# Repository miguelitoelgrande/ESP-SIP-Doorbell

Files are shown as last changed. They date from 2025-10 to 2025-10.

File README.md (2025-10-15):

# ESP SIP Doorbell - Getting Started Guide
Attach an ESP8266 or ESP32 board to a classic doorbell and use SIP protocol to make the phones connected to a FritzBox ring.

This ESP8266-based doorbell connects to your FritzBox (or other SIP server) and makes instant phone calls when triggered. The device prioritizes the doorbell function above all else - when powered on or reset, it immediately attempts to connect and ring your phones.

- Hardware setup can be found here: https://www.reichelt.de/magazin/projekte/smarte-tuerklingel/
- or: https://www.heise.de/select/ct/2017/17/1502995489716437
- or: https://www.heise.de/select/ct/2018/17/1534215254552977
- or: http://www.roehrenkramladen.de/Tuerklingel/TK-FB-V1a-1.html
There are probably even board schematics around, but breadboard-style wiring should be fine.

And again: This ESP-Software is **not** TR064 based, but uses *SIP* for simplicity and security.

---

## ⚡ Key Features
- Immediate SIP call on wake/reset: SIP initialization and call within seconds
- All configuration and management happens AFTER the call. Also the first configuration
- Starts an Access Point for the initial configuration (see below)
- **Serial Debug**: Traditional UART debugging at 115200 baud
- **WebSerial**: Browser-based debug console accessible via web interface (especially, if you cannot physically connect to the board)
- Both can be enabled/disabled independently via configuration
- Persistent storage of last 100 doorbell events
- Automatic time sync after initial call; configurable NTP server (default: pool.ntp.org) and timezone offset
- Configurable timezone offset
- **Smart Power Management**: Configurable deep sleep timeout (default: 180 seconds)
- Set timeout to 0 to disable deep sleep
- Wake on hardware reset (doorbell button)
- **Flexible Network Configuration**: DHCP or static IP, WiFi station mode for normal operation
- **Automatic AP fallback** when WiFi connection fails
- Web-based configuration portal, status, past events, WebSerial always available
- **Complete SIP Integration**: Compatible with FritzBox and standard SIP servers
- Configurable ring duration (5-120 seconds) and dial text

---

## 🚀 First-Time Setup

### Hardware and Software Requirements
- ESP8266 board (ESP-01, NodeMCU, Wemos D1, etc.)
- or ESP32 board (e.g. a tiny ESP32-C3 SuperMini will do)
- USB power or battery power supply
- Adapter to connect to existing, physical door bell circuit (with AC tansformer)
- Connect the Doorbell Button circuit between GPIO14 and GND. Will bring the ESP out of Light Sleep
- OBSOLETE: Doorbell button connected between RST (Reset) and GND - TODO: Might change to better solution
- OBSOLETE: For deep sleep wake: RST pin connected to doorbell button circuit
- Compile with **Arduino IDE** (.ino is the Sketch File, add the SIP.h and SIP.cpp)

### Initial Configuration

0. **Register Settings at FritzBox**
   - Ensure, you have your WIFI SSID and password at hand.
   - !! Needs to be a static IP in main Fritz network, not guest !!
   - You will also need the IP of your FritzBox (192.168.xx.xx).
   - If you decide to do the Fritzbox-sided registration of the IP-Doorbell first (see below), you should have the SIP user and SIP password as well. Otherwise, enter later.

2. **Power on the ESP8266**
   - On first boot, default WiFi credentials won't work
   - Device automatically starts AP mode for configuration

3. **Connect to the Configuration AP**
   - SSID: **`ESP-Doorbell-Config`**
   - Password: **`12345678`**
   - _Note: If you connect with your mobile phone, you might have to confirm, you want to stay connected to a netwok without internet access!_
   - Device IP: `192.168.4.1` (use Chrome), e.g. on a mobile phone in **same** network

4. **Open the Configuration Portal**
   - Open browser and navigate to: **`http://192.168.4.1`**
   - You'll see the main configuration page

5. **Configure WiFi Settings**
   - **SSID**: Your home WiFi network name
   - **Password**: Your WiFi password
   - **Hostname**: Device hostname (default: ESP-Doorbell)

6. **Configure Network Settings**
   - **Use DHCP**: Check for automatic IP (static IP recommended for most users - speeds up the startup)
   - **Static IP**: the static IP of the doorbell (e.g., 192.168.178.123), if DHCP is unchecked.. TODO: could be removed at all?
   - **Router/Gateway**: Your FritzBox IP (e.g., 192.168.178.1)
   - **Subnet Mask**: Usually 255.255.255.0

7. **Configure SIP Settings** (Critical!)
   - **SIP Port**: Usually 5060 (FritzBox default)
   - **SIP User**: SIP username as configured at FritzBox (e.g., "tuerklingel")
   - **SIP Password**: SIP password from FritzBox
   - **Dial Number**: Number to dial (e.g., **9 to ring at all phones, or specific extension, e.g. "1" - as configured at FritzBox)
   - **Dial Text**: Caller ID text (e.g., "Front Door")
   - **Ring Duration**: How long phones should ring (default: 30 seconds)

8. **Configure Debug Options**
   - **Serial Debug**: Enable for USB/UART debugging
   - **WebSerial Debug**: Enable for browser-based debug console
   - Both can be enabled simultaneously

9. **Configure Time Settings**
   - **NTP Server**: Time server (default: pool.ntp.org)
   - **Timezone Offset**: Seconds from UTC
     - UTC+1 (CET): 3600
     - UTC+2 (CEST): **7200**

10. **Configure Power Management**
   - **Sleep Timeout**: Seconds before deep sleep (default: 180)
   - Set to 0 to disable deep sleep
   - Device stays awake longer when accessed via web interface

11. **Save Configuration**
    - Click "Save & Reboot"
    - Device will reboot in 10 seconds
    - If WiFi connection succeeds, AP mode will be disabled
    - If WiFi fails, AP mode will remain active for reconfiguration
---

## 📞 FritzBox SIP Configuration for the doorbell

Other VoIP capable routers potentially similar (or worldwide VoIP services?)

### Important: The Doorbell needs a fixed IP address. Register at FritzBox after first connect to WIFI and use above.

### Creating a Doorbell Extension

 ### **Log into FritzBox**
   - Navigate to `http://fritz.box`
   - Login to your **FritzBox** admin portal.
   - Go to **"Telephony"** -> **"Telephony Devices"** -> **"Configure New Device"**.
   - Choose **"Door intercom system"** and **Next**.

   ### **Register new Device/SIP credentials**
      + Port: "LAN / Wi-Fi (IP door intercom system)".
      + Name: Tuerklingel.
   
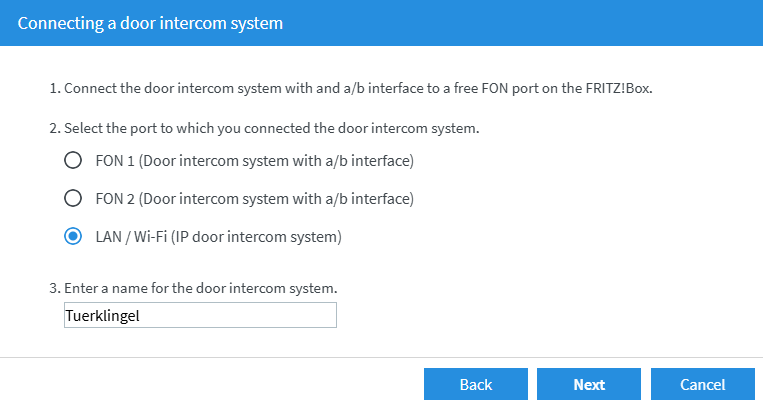
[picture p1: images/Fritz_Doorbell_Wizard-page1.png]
image info
   
   Register a new "Intercom" IP Device

   ### SIP user and Password (also note the IP of your FritzBox)
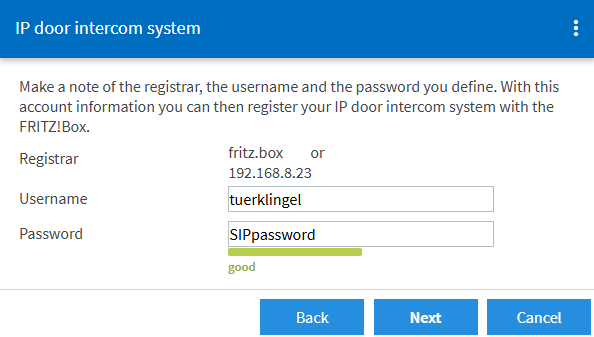
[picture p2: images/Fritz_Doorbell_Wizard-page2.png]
image info
   

   ### We need this telephone number for the configuration on the ESP.
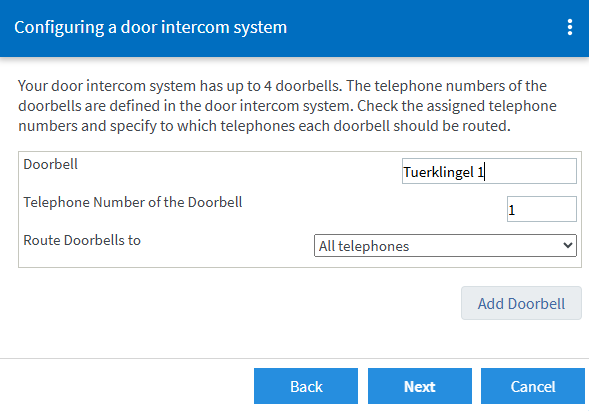
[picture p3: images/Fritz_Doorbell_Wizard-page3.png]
image info
   

   ### You could route this to all phones or a subset of phones.
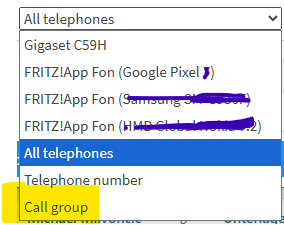
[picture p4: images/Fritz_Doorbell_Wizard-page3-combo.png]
image info
   

   ### Check the Settings and apply
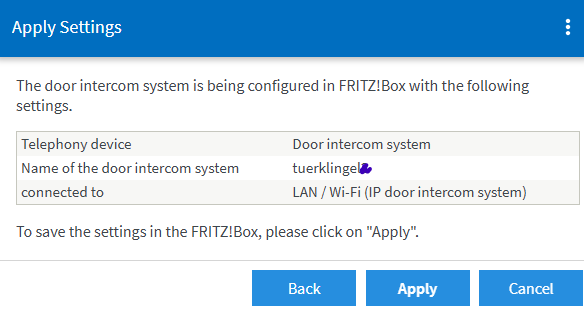
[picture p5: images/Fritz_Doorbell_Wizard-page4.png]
image info
   

   ### List of all registered devices. You can edit anytime with the pen-symbol:
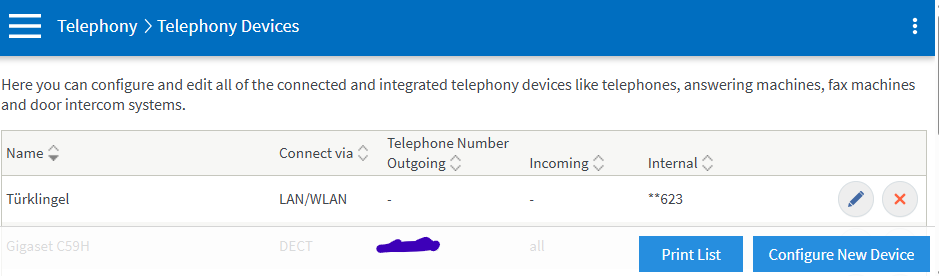
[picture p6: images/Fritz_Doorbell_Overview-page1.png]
image info
   

   ### Leave the lower part empty (..for the next fancy project with ESP32-CAM?)
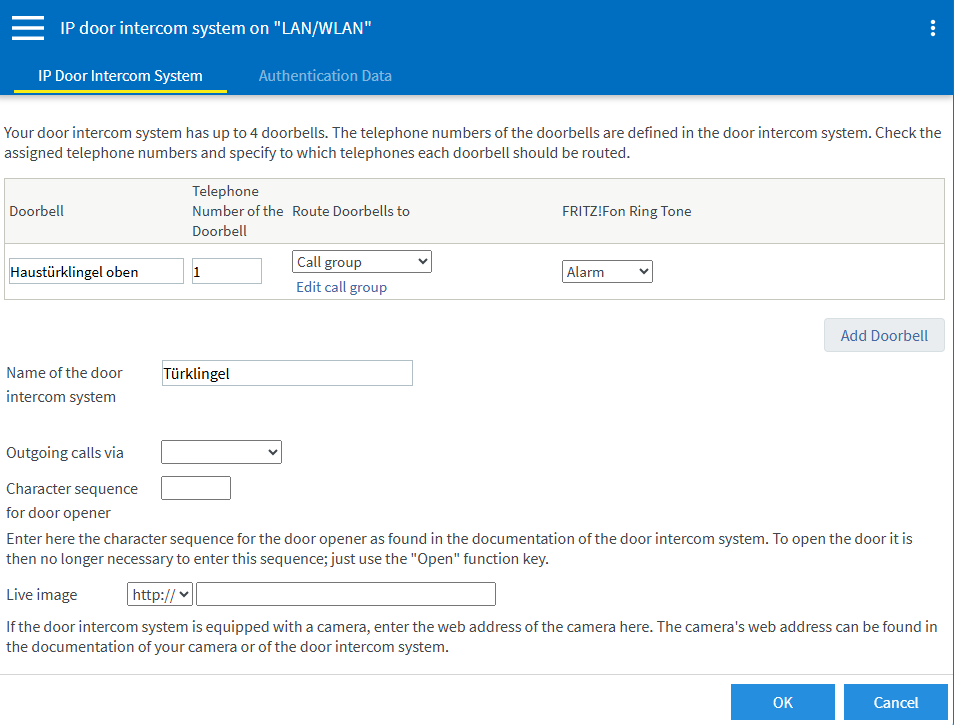
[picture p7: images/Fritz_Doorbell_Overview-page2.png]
image info
   

   ### If you forgot to note your SIP-passord/credentials, change here:
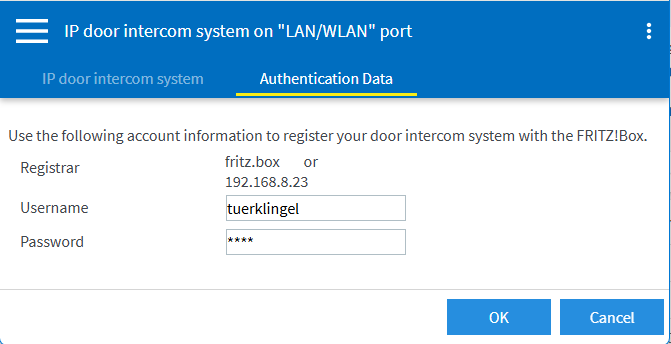
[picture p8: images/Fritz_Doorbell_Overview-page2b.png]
image info
   
   
---

## 📝 Configuration Quick Reference

| Setting | Default | Notes |
|---|---|---|
| WiFi SSID | Your-WiFi-SSID | Must configure |
| WiFi Password | Your-WiFi-Password | Must configure |
| Hostname | ESP-Doorbell | Optional |
| DHCP | Disabled | Enable for simplicity |
| Static IP | 192.168.178.123 | Only if DHCP off |
| Router/Gateway | 192.168.178.1 | FritzBox IP |
| SIP Port | 5060 | Standard |
| SIP User | tuerklingel | From FritzBox |
| SIP Password | xxxxxxx | From FritzBox |
| Dial Number | **9 | All phones |
| Ring Duration | 30 seconds | Adjust as needed |
| Serial Debug | Enabled | For USB debugging |
| WebSerial Debug | Enabled | For remote debugging |
| NTP Server | pool.ntp.org | Time server |
| Timezone | 3600 | UTC+1 (CET) |
| Sleep Timeout | 180 seconds | 3 minutes |
| AP SSID | ESP-Doorbell-Config | Change if desired |
| AP Password | 12345678 | Change immediately! |

---

## 🎯 Quick Start Summary

1. Power on ESP8266
2. Connect to `ESP-Doorbell-Config` WiFi (password: `12345678`)
3. Open `http://192.168.4.1` in browser
4. Configure WiFi and SIP settings
5. Save and reboot
6. Press doorbell button to test
7. Check event log and status page
8. Adjust settings as needed

---

---

## 🌐 Web Interface

#### Main Configuration Page (`/`)
- Complete device configuration, including WiFi, SIP, debug, and power settings
- Links to other management pages

#### Status Page (`/status`)
- Real-time information, like WiFi connection details, last doorbell call status

#### Event Log (`/events`)
- Shows the history of the doorbell events

#### WebSerial Console (`/webserial`)
- Live debug output in browser, if WebSerial enabled in config
- All serial debug messages
- Auto-refreshes every 5 seconds

---

## 🐛 Troubleshooting

- Enable Debug Output, Serial and WebSerial on config page.
- Check WiFi Connection, needs to be with static IP in main Fritz network, not guest
- Double-check SIP credentials, username and password

### Can't Access Configuration

1. **WiFi Connection Failed**
   - Device will automatically start AP mode
   - Connect to `ESP-Doorbell-Config` network
   - Access `http://192.168.4.1`

2. **Forgot IP Address**
   - Check your router's DHCP client list
   - Look for hostname (default: ESP-Doorbell)
   - Or power cycle to trigger AP mode

3. **AP Mode Not Working**
   - Reset device completely
   - Check AP settings in configuration
   - Default AP: `ESP-Doorbell-Config` / `12345678`

### Deep Sleep Issues

1. **Device Won't Wake**
   - Verify RST pin is connected to doorbell button
   - Check for proper pull-up resistor (10kΩ)
   - Try setting sleep timeout to 0 (disabled)

2. **Device Sleeps Too Quickly**
   - Increase sleep timeout in configuration
   - Default: 180 seconds (3 minutes)
   - Any web access resets the timeout

---

## 🔌 TODO: Connecting to the doorbell

### Last minute change...

Now, the Doorbell button (circuit) needs to connect to a GPIO pin found in the code (DOORBELL_PIN). This allows for WIFI wakeup and also unwanted Reset action during EEPROM ops , etc. (to be on the safe side)

GPIO14 (== D5 on NodeMCU), Connect doorbell button here (active LOW with pullup)

### Basic Wiring (Power-on Reset)
```
Power Supply → 3.3V/5V and GND
```
### Deep Sleep Wiring (Recommended)
```
Doorbell Button → RST pin and GND (via 10kΩ pull-up)
Additional: Button → GPIO0 (for programming mode)
Power Supply → 3.3V/5V and GND
```

### LED Indicator
- Built-in LED on GPIO2 (D4) - inverted logic
- ON = SIP call in progress
- Blinks = various status indicators

Schematics:
  Schematics

... could look like this (with ESP32-C3 Supermini):
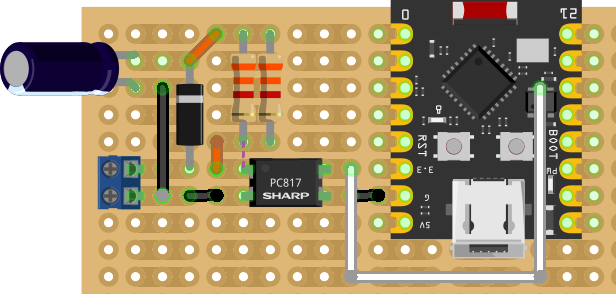
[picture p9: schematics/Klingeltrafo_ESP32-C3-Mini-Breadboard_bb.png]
Sample Breadboard


```

> Hauptbestandteil ist ein Optokoppler (PC817), der zwei Stromkreise über eine Lichtbrücke trennt. Damit die LED des PC817 die korrekte Betriebsspannung von 1,2 Volt erhält, ist ein passender Vorwiderstand von 330 Ohm (8 Volt), 560 Ohm (12 Volt) oder 1,2 Kiloohm (24 Volt) erforderlich. Bei 24 V müsste der Widerstand eigentlich 0,5 W aushalten, da in der Regel aber nur wenige Sekunden geklingelt wird, hält auch die 0,25-W-Variante stand. Hat man jedoch Dauerdrücker im Freundeskreis, sollte man vorsichtshalber die 0,5-W-Variante wählen.

> Der Vorwiderstand senkt die Spannung in Durchlassrichtung der Optokoppler-LED zwar ab, jedoch ist bei Wechselspannung auch die Gegenrichtung zu berücksichtigen. Die Durchbruchspannung der LED im PC817 beträgt lediglich 6 Volt. Eine antiparallele Diode führt die gegenläufige Wechselspannung über den Widerstand ab und verhindert so, dass der Optokoppler beschädigt wird. Erfahrene Bastler werden hier schnell bemerken, dass der Ausgang des Optokopplers beim Betätigen des Klingetasters mit der Netzfrequenz pulsiert. Für den Raspberry Pi ist dies jedoch kein Problem. Mittels Polling-Schleife erkennt er die Impulse zuverlässig.

_Source: https://www.heise.de/select/ct/2017/17/1502995489716437_

obsolete (new version has one universal set of two 1/4W resistors):
| DoorBell Transformer<br>(AC current)    |  R1     |
|-----------------|----------|
| 8 V            | 330 Ohm  |
| 12 V           | 560 Ohm  |
| 24 V           | 1,2 kOhm |

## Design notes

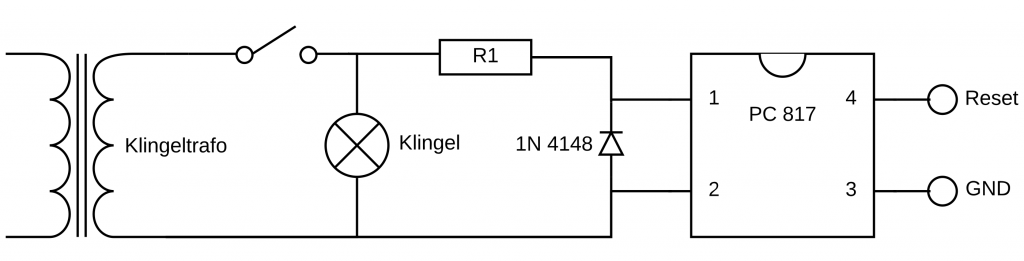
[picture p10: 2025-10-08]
schematics/Klingel.svg_-1024x261.png

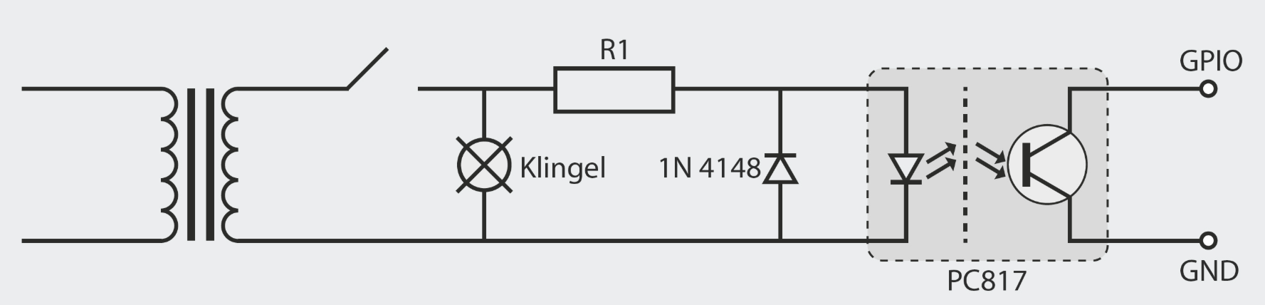
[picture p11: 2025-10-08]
schematics/Klingelschaltung-Optokoppler.png

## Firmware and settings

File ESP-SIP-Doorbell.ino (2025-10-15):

/* ====================================================================
   ESP SIP Doorbell for FritzBox (ESP32 and ESP8266).
   see: https://github.com/miguelitoelgrande/ESP-SIP-Doorbell

  Coded with some AI assistance and inspiration of similar projects (see Readme.md)

   Features:
   - Immediate SIP call on power-on/reset (doorbell priority)
   - Serial and WebSerial debugging options
   - Time synchronization (NTP/FritzBox)
   - Persistent event logging (last 100 doorbell events)
   - Web-based configuration portal with AP fallback
   - Deep sleep with wake on hardware reset
   - ESP32 also supported
   - Tested with "Generic ESP8266 Module" (Dev Board)
   - "ESP32C3 Dev Module"- ESP32-C3 SuperMini ["USB CDC On Boot" to "Enable" for USB logging!]
 * ====================================================================*/


#include <EEPROM.h>
#include <time.h>
#include <WiFiUdp.h>
#include "Sip.h"

// Board-specific includes
#if defined(ESP8266)
  #include <ESP8266WiFi.h>
  #include <ESP8266WebServer.h>
  #define WebServer ESP8266WebServer
#elif defined(ESP32)
  #include <WiFi.h>
  #include <WebServer.h>
#else
  #error "This code requires ESP8266 or ESP32"
#endif

// ====================================================================
// DEBUG CONFIGURATION
// ====================================================================
#define DEBUG_SERIAL_BAUD 115200

// Forward declarations for debug functions
void debugPrint(const char* msg);
void debugPrintln(const char* msg);
void debugPrintf(const char* format, ...);

// Debug macros - will respect config settings
#define DEBUG_PRINT(x) debugPrint(x)
#define DEBUG_PRINTLN(x) debugPrintln(x)
#define DEBUG_PRINTF(...) debugPrintf(__VA_ARGS__)


// ====================================================================
// CONFIGURATION STRUCTURE
// ====================================================================
#define CONFIG_VERSION "CFG3"
#define CONFIG_START 0

struct Config {
  char version[5];
  
  // WiFi settings
  char ssid[32];
  char password[64];
  char hostname[32];
  
  // Network settings
  bool useDHCP;
  char ip[16];
  char router[16];
  char subnet[16];
  
  // SIP settings
  int sipPort;
  char sipUser[32];
  char sipPassword[64];
  char dialNumber[16];
  char dialText[64];
  int ringDuration;
  
  // Deep sleep settings
  int wifiTxPower;  // was dummy - WiFi TX power 0-100 (percentage)
  int lightSleepEnabled;  // 0=disabled, 1=enabled
  int inactivitySleepTimeout;  // Seconds of inactivity before light sleep
  
  // AP mode settings
  char apSSID[32];
  char apPassword[64];
  
  // Debug settings
  bool debugSerial;
  bool debugWebSerial;
  
  // Time settings
  char ntpServer[64];
  int timezoneOffset;  // Offset in seconds from UTC
};

Config config;

// ====================================================================
// EVENT LOG STRUCTURE
// ====================================================================
#define MAX_EVENTS 100  // Increased from 50 since we removed timeStr
#define EVENTLOG_START 1024  // Leave space for config expansion

struct DoorbellEvent {
  unsigned long timestamp;  // Unix timestamp
  bool sipSuccess;         // Was SIP call successful
//  uint8_t wakeReason;      // Reset reason (using uint8_t to save space)
};

struct EventLog {
  int count;               // Total events logged
  int writeIndex;          // Next write position (ring buffer)
  DoorbellEvent events[MAX_EVENTS];
};

EventLog eventLog;

// ====================================================================
// GLOBAL VARIABLES
// ====================================================================

// Board-specific includes
#if defined(ESP8266)
   ESP8266WebServer server(80);
   #define LED_PIN 2     //  2 ESP8266   LED_BUILTIN
#elif defined(ESP32)
   WebServer server(80);
   #define LED_PIN 8     //  8- ESP32C3??  LED_BUILTIN
#else
  #error "This code requires ESP8266 or ESP32"
#endif

WiFiUDP ntpUDP;

// ====================================================================
// HARDWARE CONFIGURATION
// ====================================================================

#define DOORBELL_PIN 10 //   // former: GPIO14 = D5 on NodeMCU, change as needed. Connect doorbell button here (active LOW with pullup)

// Debounce settings
#define DEBOUNCE_MS 500  // Minimum time between doorbell presses
#define BUTTON_HOLD_MS 100  // Button must be pressed this long to be valid

// Watchdog and recovery settings
#define WIFI_RECONNECT_INTERVAL 60000    // Check WiFi every 60 seconds
#define MAX_FAILED_CALLS 3               // Reset after 3 failed calls in a row
#define UPTIME_RESTART_DAYS 7            // Preventive restart after 7 days
#define WIFI_CONNECT_TIMEOUT 30000       // 30 seconds to connect

unsigned long lastActivityTime = 0;
unsigned long lastDoorbellPress = 0;
unsigned long lastWiFiCheck = 0;        // NEW
int consecutiveFailedCalls = 0;         // NEW
bool sipCallAttempted = false;
bool sipCallSuccess = false;
bool doorbellPressed = false;
volatile bool doorbellInterruptFlag = false;
Sip* aSip = nullptr;

char caSipIn[2048];
char caSipOut[2048];

// WebSerial buffer
#define WEBSERIAL_BUFFER_SIZE 8192
char webSerialBuffer[WEBSERIAL_BUFFER_SIZE];
int webSerialIndex = 0;

// ====================================================================
// DEBUG FUNCTIONS (respect config settings)
// ====================================================================

void addToWebSerialBuffer(const char* msg) {
  if (!config.debugWebSerial) return;
  
  int len = strlen(msg);
  if (webSerialIndex + len >= WEBSERIAL_BUFFER_SIZE - 1) {
    // Buffer full, shift content
    int shift = WEBSERIAL_BUFFER_SIZE / 2;
    memmove(webSerialBuffer, webSerialBuffer + shift, WEBSERIAL_BUFFER_SIZE - shift);
    webSerialIndex -= shift;
  }
  
  strcpy(webSerialBuffer + webSerialIndex, msg);
  webSerialIndex += len;
}

void debugPrint(const char* msg) {
  if (config.debugSerial) {
    Serial.print(msg);
  }
  if (config.debugWebSerial) {
    addToWebSerialBuffer(msg);
  }
}

void debugPrintln(const char* msg) {
  if (config.debugSerial) {
    Serial.println(msg);
  }
  if (config.debugWebSerial) {
    addToWebSerialBuffer(msg);
    addToWebSerialBuffer("\n");
  }
}

void debugPrintf(const char* format, ...) {
  char buffer[256];
  va_list args;
  va_start(args, format);
  vsnprintf(buffer, sizeof(buffer), format, args);
  va_end(args);
  
  if (config.debugSerial) {
    Serial.print(buffer);
  }
  if (config.debugWebSerial) {
    addToWebSerialBuffer(buffer);
  }
}

// ====================================================================
// FUNCTION DECLARATIONS
// ====================================================================
void loadConfig();
void saveConfig();
void setDefaultConfig();
void loadEventLog();
void saveEventLog();
void logDoorbellEvent(bool success);
void setupAP();
void setupWebServer();
void handleRoot();
void handleSave();
void handleStatus();
void handleEvents();
void handleWebSerial();
void connectWiFi();
void syncTime();
void makeEmergencySIPCall();
void checkLightSleep();
void IRAM_ATTR doorbellISR();
void handleDoorbellPress();
void blinkLED(int times, int delayMs);
String formatTime(unsigned long timestamp);
String formatUptime(time_t uptime); // ... more readable than seconds...


// ====================================================================
// WATCHDOG AND RECOVERY FUNCTIONS
// ====================================================================

void checkWiFiHealth() {
  if (millis() - lastWiFiCheck < WIFI_RECONNECT_INTERVAL) {
    return; // Not time to check yet
  }
  
  lastWiFiCheck = millis();
  
  if (WiFi.status() != WL_CONNECTED) {
    DEBUG_PRINTLN("[WATCHDOG] WiFi disconnected! Attempting reconnect...");
    
    // Cleanup SIP if active
    if (aSip != nullptr) {
      delete aSip;
      aSip = nullptr;
      DEBUG_PRINTLN("[WATCHDOG] Cleaned up SIP connection");
    }
    
    // Force disconnect and reconnect
    WiFi.disconnect();
    delay(500);
    
    WiFi.mode(WIFI_STA);
    WiFi.hostname(config.hostname);
    
    if (!config.useDHCP) {
      IPAddress ip, gw, subnet, dns;
      if (ip.fromString(config.ip) && gw.fromString(config.router) && 
          subnet.fromString(config.subnet) && dns.fromString(config.router)) {
        WiFi.config(ip, gw, subnet, dns);
      }
    }
    
    WiFi.begin(config.ssid, config.password);
    setWiFiTxPower();  // Set TX power after WiFi.begin()
    
    unsigned long startAttempt = millis();
    while (WiFi.status() != WL_CONNECTED && millis() - startAttempt < WIFI_CONNECT_TIMEOUT) {
      delay(500);
      DEBUG_PRINT(".");
    }
    
    if (WiFi.status() == WL_CONNECTED) {
      DEBUG_PRINTLN("\n[WATCHDOG] WiFi reconnected successfully!");
      DEBUG_PRINTF("[WATCHDOG] IP: %s, RSSI: %d dBm\n", 
                   WiFi.localIP().toString().c_str(), WiFi.RSSI());
      
      // Resync time after reconnect
      syncTime();
      
      // Reset consecutive failures on successful reconnect
      consecutiveFailedCalls = 0;
    } else {
      DEBUG_PRINTLN("\n[WATCHDOG] WiFi reconnect FAILED!");
      consecutiveFailedCalls++;
      
      // If can't reconnect after multiple attempts, restart
      if (consecutiveFailedCalls >= MAX_FAILED_CALLS) {
        DEBUG_PRINTLN("[WATCHDOG] Too many failures, restarting device...");
        delay(1000);
        ESP.restart();
      }
    }
  } else {
    // WiFi is connected, check signal quality
    int rssi = WiFi.RSSI();
    if (rssi < -85) {
      DEBUG_PRINTF("[WATCHDOG] WARNING: Weak WiFi signal (%d dBm)\n", rssi);
    }
  }
}

void checkUptimeReset() {
  // Preventive restart after configured days of uptime
  unsigned long uptimeSeconds = millis() / 1000;
  unsigned long uptimeDays = uptimeSeconds / 86400;
  
  if (uptimeDays >= UPTIME_RESTART_DAYS) {
    DEBUG_PRINTF("[WATCHDOG] Preventive restart after %lu days uptime\n", uptimeDays);
    logDoorbellEvent(true); // Log a "maintenance" event
    delay(1000);
    ESP.restart();
  }
}

void reinitializeSIP() {
  DEBUG_PRINTLN("[WATCHDOG] Reinitializing SIP connection...");
  
  if (aSip != nullptr) {
    delete aSip;
    aSip = nullptr;
  }
  
  if (WiFi.status() == WL_CONNECTED) {
    aSip = new Sip(caSipOut, sizeof(caSipOut));
    aSip->Init(config.router, config.sipPort, 
               config.useDHCP ? WiFi.localIP().toString().c_str() : config.ip, 
               config.sipPort, config.sipUser, config.sipPassword, config.ringDuration);
    DEBUG_PRINTLN("[WATCHDOG] SIP reinitialized");
  } else {
    DEBUG_PRINTLN("[WATCHDOG] Cannot reinitialize SIP - WiFi not connected");
  }
}


void setWiFiTxPower() {
  // Constrain to valid range
  int powerPercent = constrain(config.wifiTxPower, 0, 100);
  
  #if defined(ESP8266)
    // ESP8266: 0 to 20.5 dBm (82 = 20.5dBm max)
    float dbm = (powerPercent / 100.0) * 20.5;
    WiFi.setOutputPower(dbm);
    DEBUG_PRINTF("[WIFI] TX Power set to %.1f dBm (%d%%)\n", dbm, powerPercent);
  #elif defined(ESP32)
    // ESP32: 2 to 20 dBm (using WiFi.setTxPower)
    int8_t dbm = 2 + ((powerPercent / 100.0) * 18);
    WiFi.setTxPower((wifi_power_t)dbm);
    DEBUG_PRINTF("[WIFI] TX Power set to %d dBm (%d%%)\n", dbm, powerPercent);
  #endif
}
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
void loop() {
  static unsigned long lastDebugTime = 0;
  
  // Check for doorbell interrupt
  if (doorbellInterruptFlag) {
    doorbellInterruptFlag = false;
    handleDoorbellPress();
  }
  
  server.handleClient();
  
  // Watchdog: Check WiFi health
  checkWiFiHealth();
  
  // Watchdog: Check if preventive restart needed
  checkUptimeReset();
  
  // Handle SIP packets if active
  if (aSip != nullptr) {
    int packetSize = aSip->Udp.parsePacket();
    if (packetSize > 0) {
      caSipIn[0] = 0;
      packetSize = aSip->Udp.read(caSipIn, sizeof(caSipIn));
      if (packetSize > 0) {
        caSipIn[packetSize] = 0;
      }
      lastActivityTime = millis();
    }
    aSip->HandleUdpPacket((packetSize > 0) ? caSipIn : 0);
  }
  
  checkLightSleep();
  delay(10);
}


// ====================================================================
// CONFIGURATION FUNCTIONS
// ====================================================================

void loadConfig() {
  EEPROM.get(CONFIG_START, config);
  
  if (strcmp(config.version, CONFIG_VERSION) != 0) {
    Serial.println("[CONFIG] No valid config, loading defaults");
    setDefaultConfig();
    saveConfig();
  } else {
    // Debug: dump loaded configuration
    Serial.println("[CONFIG] Configuration loaded:");
    Serial.printf("[CONFIG]   Version: %s\n", config.version);
    Serial.printf("[CONFIG]   SSID: '%s' (len=%d)\n", config.ssid, strlen(config.ssid));
    Serial.printf("[CONFIG]   Hostname: '%s'\n", config.hostname);
    Serial.printf("[CONFIG]   DHCP: %s\n", config.useDHCP ? "true" : "false");
    Serial.printf("[CONFIG]   Static IP: %s\n", config.ip);
    Serial.printf("[CONFIG]   Router: %s\n", config.router);
    Serial.printf("[CONFIG]   Subnet: %s\n", config.subnet);
    Serial.printf("[CONFIG]   SIP Port: %d\n", config.sipPort);
    Serial.printf("[CONFIG]   SIP User: '%s'\n", config.sipUser);
  }
}

void saveConfig() {
  strcpy(config.version, CONFIG_VERSION);
  EEPROM.put(CONFIG_START, config);
  EEPROM.commit();
}

void setDefaultConfig() {
  strcpy(config.version, CONFIG_VERSION);
  
  strcpy(config.ssid, "Your-WiFi-SSID");
  strcpy(config.password, "Your-WiFi-Password");
  strcpy(config.hostname, "ESP-Doorbell");
  
  config.useDHCP = false;
  strcpy(config.ip, "192.168.178.123");
  strcpy(config.router, "192.168.178.1");
  strcpy(config.subnet, "255.255.255.0");
  
  config.sipPort = 5060;
  strcpy(config.sipUser, "tuerklingel");
  strcpy(config.sipPassword, "xxxxxxx");
  strcpy(config.dialNumber, "**9");
  strcpy(config.dialText, "Tuerklingel 1");
  config.ringDuration = 30;
  
  config.wifiTxPower = 75;  // TX power percentage
  config.lightSleepEnabled = 1;
  config.inactivitySleepTimeout = 300;  // 5 minutes
  
  strcpy(config.apSSID, "ESP-Doorbell-Config");
  strcpy(config.apPassword, "12345678");
  
  config.debugSerial = true;
  config.debugWebSerial = true;
  
  strcpy(config.ntpServer, "pool.ntp.org");
  config.timezoneOffset = 3600; // UTC+1
}

// ====================================================================
// EVENT LOG FUNCTIONS
// ====================================================================

void loadEventLog() {
  DEBUG_PRINTF("[EVENT] Loading event log from EEPROM address %d\n", EVENTLOG_START);
  DEBUG_PRINTF("[EVENT] EventLog structure size: %d bytes\n", sizeof(EventLog));
  
  EEPROM.get(EVENTLOG_START, eventLog);
  
/*
    // MM: quick and dirty flush old log..
    eventLog.count = -1;
    eventLog.writeIndex = -1;
*/
  /*
  DEBUG_PRINTF("[EVENT] Raw loaded values - count=%d, writeIndex=%d\n", 
               eventLog.count, eventLog.writeIndex);
  */

  // Validate
  if (eventLog.count < 0 || eventLog.count > 100000 || 
      eventLog.writeIndex < 0 || eventLog.writeIndex >= MAX_EVENTS) {
    DEBUG_PRINTLN("[EVENT] Invalid event log detected, resetting");
    DEBUG_PRINTF("[EVENT]   Invalid count: %d (expected 0-100000)\n", eventLog.count);
    DEBUG_PRINTF("[EVENT]   Invalid writeIndex: %d (expected 0-%d)\n", eventLog.writeIndex, MAX_EVENTS-1);
    
    eventLog.count = 0;
    eventLog.writeIndex = 0;
    memset(eventLog.events, 0, sizeof(eventLog.events));
    saveEventLog();
  } else {
    DEBUG_PRINTF("[EVENT] ✓ Loaded valid event log: %d total events, writeIndex=%d\n", 
                 eventLog.count, eventLog.writeIndex);
    
    // Debug: show last few events
    if (eventLog.count > 0) {
      int toShow = min(3, min(eventLog.count, MAX_EVENTS));
      DEBUG_PRINTF("[EVENT] Last %d events:\n", toShow);
      for (int i = 0; i < toShow; i++) {
        int index = (eventLog.writeIndex - 1 - i + MAX_EVENTS) % MAX_EVENTS;
        DoorbellEvent& evt = eventLog.events[index];
        DEBUG_PRINTF("[EVENT]   #%d: %s - %s\n", 
                     eventLog.count - i, 
                     formatTime(evt.timestamp).c_str(),
                     evt.sipSuccess ? "SUCCESS" : "FAILED");
      }
    }
  }
}

void saveEventLog() {
  DEBUG_PRINTF("[EVENT] saveEventLog() called - saving count=%d, writeIndex=%d\n", 
               eventLog.count, eventLog.writeIndex);
  EEPROM.put(EVENTLOG_START, eventLog);
  bool result = EEPROM.commit();
  DEBUG_PRINTF("[EVENT] saveEventLog() commit result: %s\n", result ? "SUCCESS" : "FAILED");
}

void logDoorbellEvent(bool success) {
  time_t now = time(nullptr);
  
  /*
  DEBUG_PRINTF("[EVENT] Logging event - timestamp=%lu, success=%d\n", 
               (unsigned long)now, success ? 1 : 0);
  DEBUG_PRINTF("[EVENT] Current state BEFORE - count=%d, writeIndex=%d\n", 
               eventLog.count, eventLog.writeIndex);
  */

  DoorbellEvent event;
  event.timestamp = now;
  event.sipSuccess = success;
  
  // Store in ring buffer at current write position
  eventLog.events[eventLog.writeIndex] = event;
  // DEBUG_PRINTF("[EVENT] Stored event at index %d (timestamp=%lu, success=%d)\n", eventLog.writeIndex, (unsigned long)event.timestamp, event.sipSuccess ? 1 : 0);
  
  // Update counters BEFORE saving
  int oldWriteIndex = eventLog.writeIndex;
  int oldCount = eventLog.count;
  
  eventLog.writeIndex = (eventLog.writeIndex + 1) % MAX_EVENTS;
  eventLog.count++;
  
  // DEBUG_PRINTF("[EVENT] Updated state - count=%d->%d, writeIndex=%d->%d\n", oldCount, eventLog.count, oldWriteIndex, eventLog.writeIndex);
  
  // Force flush any pending EEPROM operations
  EEPROM.commit();
  delay(10);
  
  // Now save everything to EEPROM
  EEPROM.put(EVENTLOG_START, eventLog);
  bool commitResult = EEPROM.commit();
  // DEBUG_PRINTF("[EVENT] EEPROM.commit() result: %s\n", commitResult ? "SUCCESS" : "FAILED");
  delay(50); // Give EEPROM time to settle
  
  // Verify it was saved correctly
  EventLog verify;
  EEPROM.get(EVENTLOG_START, verify);
  // DEBUG_PRINTF("[EVENT] Verification AFTER save - count=%d, writeIndex=%d\n", verify.count, verify.writeIndex);
  
  if (verify.count != eventLog.count || verify.writeIndex != eventLog.writeIndex) {
    DEBUG_PRINTLN("[EVENT] ⚠ WARNING: EEPROM verification FAILED!");
    DEBUG_PRINTF("[EVENT]   Expected: count=%d, writeIndex=%d\n", eventLog.count, eventLog.writeIndex);
    DEBUG_PRINTF("[EVENT]   Got:      count=%d, writeIndex=%d\n", verify.count, verify.writeIndex);
  } else {
    // DEBUG_PRINTLN("[EVENT] ✓ EEPROM verification PASSED");
  }
  
  DEBUG_PRINTF("[EVENT] Event #%d logged: %s - %s\n", 
               eventLog.count, formatTime(event.timestamp).c_str(), 
               success ? "SUCCESS" : "FAILED");
}

String formatTime(unsigned long timestamp) {
  if (timestamp < 1577836800) {  // Before Jan 1, 2020
    return "No time sync (ts: " + String(timestamp) + ")";
  }
  
  time_t t = (time_t)timestamp;
  struct tm* timeinfo = localtime(&t);
  
  if (timeinfo == nullptr) {
    return "Invalid time (ts: " + String(timestamp) + ")";
  }
  
  char buffer[20];
  strftime(buffer, sizeof(buffer), "%Y-%m-%d %H:%M:%S", timeinfo);
  return String(buffer);
}

// ====================================================================
// TIME SYNC FUNCTION
// ====================================================================
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

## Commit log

2025-10-08 initial commit
    ...was lazy, a couple of local experiments, also with support from KI.
2025-10-08 Update ESP-SIP-Doorbell.ino
    fixed event logging. now really persists correctly
    [ESP-SIP-Doorbell.ino]
2025-10-08 first LightSleep version
    avoids deep sleep disadvantages at a bit higher power consumption.
    Light Sleep, not DeepSleep and RST anymore...
    GPIO14 (== D5 on NodeMCU), Connect doorbell button here (active LOW with pullup)
    [ESP-SIP-Doorbell.ino]
2025-10-12 more robust/bulletproof long-term operations..
    failed after 12+ hours (WIFI...)
    changes:
    * WiFi Watchdog - Checks connection every 60s, auto-reconnects if down
    * Failed Call Recovery - Restarts device after 3 consecutive failures
    * Emergency Reconnect - Tries to reconnect WiFi when doorbell pressed
    * SIP Reinitialization - Rebuilds SIP connection after failures
    * Preventive Restart - Auto-restart after 7 days to clear any memory leaks
    * Signal Quality Monitoring - Warns about weak WiFi signal
    * Time Resync - Re-synchronizes time after WiFi reconnect
    [ESP-SIP-Doorbell.ino]
2025-10-14 supporting ESP32
    first steps...
2025-10-14 making ESP32 ready
    quick and dirty fix..
2025-10-15 ESP32-C3 Supermini Board
    not tested yet. But shows how to connect the ESP32 in a pragmatic way.
    [Klingeltrafo_ESP32-C3-Mini-Breadboard.fzz]
2025-10-15 added schematics to Readme
